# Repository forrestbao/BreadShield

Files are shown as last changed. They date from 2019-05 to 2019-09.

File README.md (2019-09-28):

# BreadShield

BreadShield is a shield that maps Arduino pins to breadboard ties without jumper wires. It inserts into both of them, firmly bridging them together mechanically and electrically.

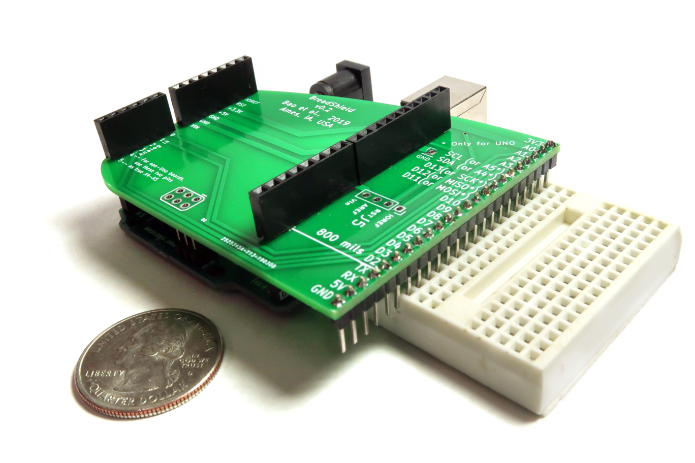
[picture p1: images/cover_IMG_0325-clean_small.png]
A breadshield


Watch [this video](https://www.youtube.com/watch?v=qSHss7gq7b0) to see BreadShield in action! 

To order, scroll down to see our distributors. 

# Why

Many projects start with connecting an Arduino and a breadboard using jumper wires. But jumper wires can easily become too many to manage, forming a mess of spaghetti that is difficult to trace, debug, and swap: 

Too mamy jumper wires can lead to a messy project that is hard to manage.

#Introducing BreadShield: The Arduino shield for breadboards

Like you, we have suffered enough. One day we asked, what if all of those messy jumper wires could become one shield? So BreadShield was born. With BreadShield, the messy project above can be simplified into: 

BreadShield connects an Arduino Uno with an HD44780 LCD with only 1 jumper wire, instead of 11 parallel jumper wires above.

# BreadShield vs. jumper wires

Connecting Arduino Uno to a HD44780 display, in jump wires. vs. in BreadShield

Connecting Arduino Uno to two servo motors, in jump wires. vs. in BreadShield

Connecting Arduino Uno to a row of LEDs, in jump wires. vs. in BreadShield

# No more choosing between shields or breadboards

Before, you cannot use shields together with breadboards because the jumper wires occupy sockets for shields. No more! With BreadShield, you can use both, simultaneously:

By BreadShield, you can use shields and breadboard together.

# Pinout of Breadshield

BreadShield pinout

# Organization of files in the repo
* KiCAD: the KiCAD files of the PCB
* demo: programs and documentations for demos
* images: some images of BreadShield

# License
BreadShield (c) by Forrest Sheng Bao et al.

BreadShield is licensed under a
Creative Commons Attribution-ShareAlike 4.0 International License.

You should have received a copy of the license along with this
work. If not, see <http://creativecommons.org/licenses/by-sa/4.0/>.

A copy of this license is in the file `license.md`.

# Where to buy
* [Tindie, by the author himself](https://www.tindie.com/products/edit/breadshield/) 
* [ARMWorks, 1 or 3-pack](https://andahammer.com/index.php?route=product/product&path=68&product_id=299)
* [Mouser](https://www.mouser.com/Search/Refine?FS=TRUE&N=4246651945+4292906361)
* [Crowd Supply](https://www.crowdsupply.com/loser/breadshield)

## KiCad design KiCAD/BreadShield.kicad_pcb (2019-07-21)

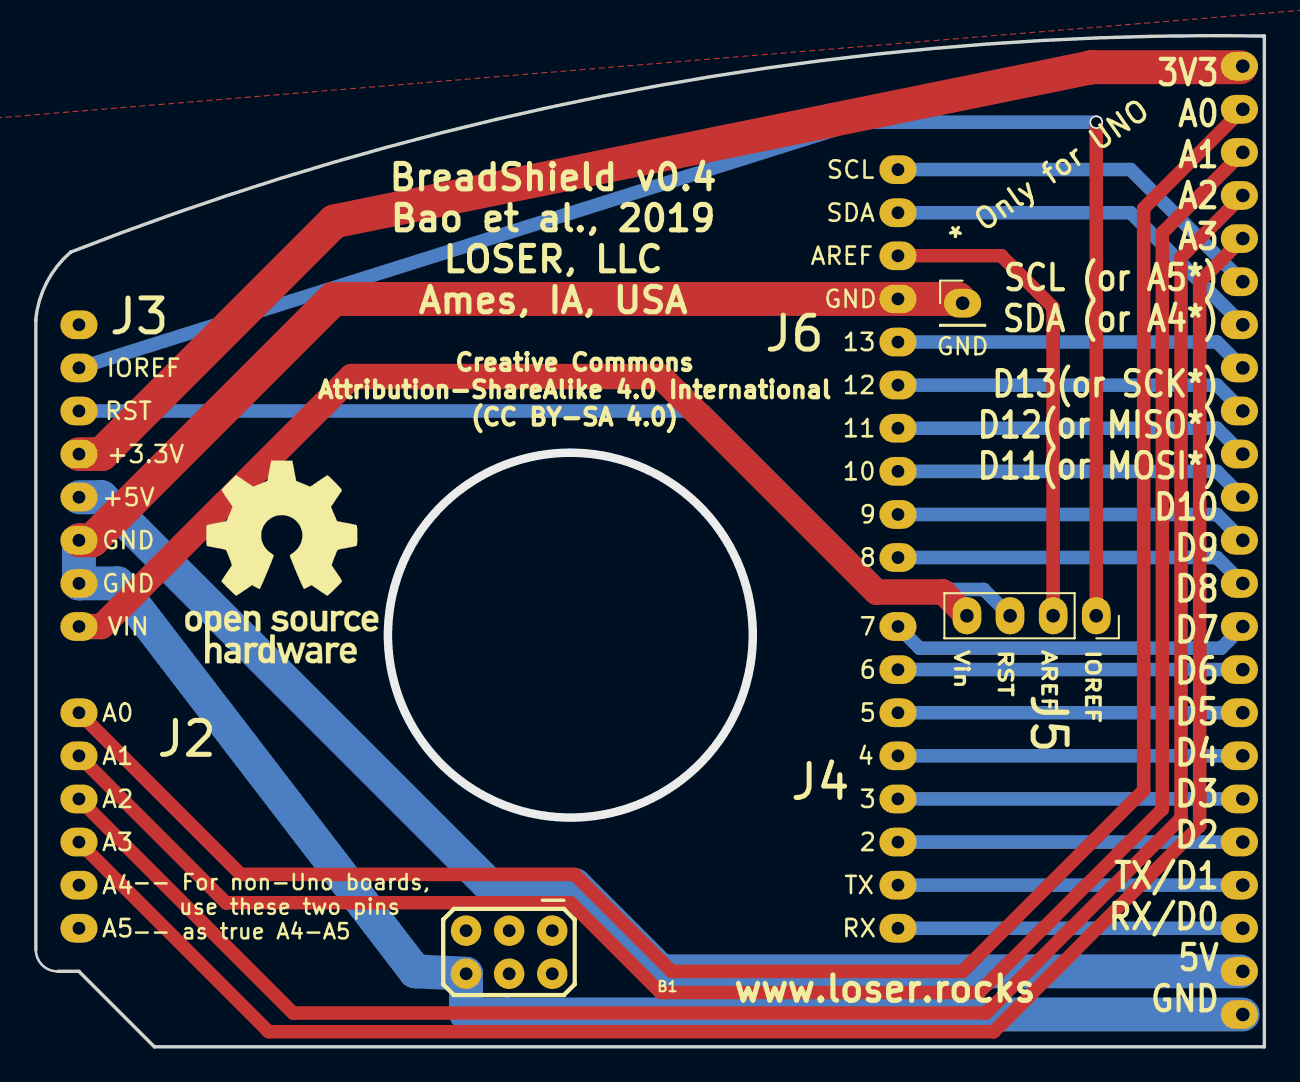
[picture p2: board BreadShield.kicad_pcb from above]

Board: 2 copper layers, 72.4 x 59.6 mm, 4 parts (1 on the bottom side), 27 nets.

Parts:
B1: ARDUINO_UNO_R3_SHIELD_ICSP; UNO_R3_SHIELD_ICSP
GND: PinHeader_1x01_P2.54mm_Vertical
J1: Conn_01x23_Male; PinHeader_1x23_P2.54mm_Vertical
J5: Conn_01x04_Female; PinSocket_1x04_P2.54mm_Vertical

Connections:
/3V3: B1.3.3V, J1.23
/5V: B1.5V, J1.2
/A0: B1.A0, J1.22
/A1: B1.A1, J1.21
/A2: B1.A2, J1.20
/A3: B1.A3, J1.19
/AREF: B1.AREF, J5.2
/D2: B1.D2, J1.5
/D3: B1.D3, J1.6
/D4: B1.D4, J1.7
/D5: B1.D5, J1.8
/D6: B1.D6, J1.9
/D7: B1.D7, J1.10
/D8: B1.D8, J1.11
/D9: B1.D9, J1.12
/D10: B1.D10, J1.13
/GND: B1.GND@, B1.GND_, GND.1, J1.1
/IOREF: B1.IORE, J5.1
/MISO_D12: B1.D12, J1.15
/MOSI_D11: B1.D11, J1.14
/RES: B1.RES, J5.3
/RX: B1.RX, J1.3
/SCK_D13: B1.D13, J1.16
/SCL_A5: B1.SCL, J1.18
/SDA_A4: B1.SDA, J1.17
/TX: B1.TX, J1.4
/Vin: B1.VIN, J5.4

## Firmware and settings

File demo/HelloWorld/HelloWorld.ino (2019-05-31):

/*

  by Forrest Sheng Bao
  for BreadShield project 
  March, 2019 

  This demo code is modified from the Hello,World example of 
  LiquidCrystal library 
  http://www.arduino.cc/en/Tutorial/LiquidCrystal

  Library originally added 18 Apr 2008
  by David A. Mellis
  library modified 5 Jul 2009
  by Limor Fried (http://www.ladyada.net)
  example added 9 Jul 2009
  by Tom Igoe
  modified 22 Nov 2010
  by Tom Igoe

 
  The circuit (different from default LiquidCrystal's):
 * VSS to GND on BreadShield  -- one end of a potentiometer
 * VDD to 5V on BreadShield  -- the other end of the potentiometer
 * VEE/V0 to RX on BreadShield -- middle pin of the potentiometer
 * RS to TX on BreadShield
 * RW to GND USE A JUMPWIRE -- not by pulling D2 to low
 * E/enable to D3 on BreadShield
 * LCD D4 pin to digital pin 8 on BreadShield
 * LCD D5 pin to digital pin 9 on BreadShield
 * LCD D6 pin to digital pin 10 on BreadShield
 * LCD D7 pin to digital pin 11 on BreadShield
 * LCD backlight Anode to digital pin 12 on BreadShield
 * LCD backlight kathode to digital pin 13 on BreadShield
 
 When programming the Arduino, please disconnect the GND pin of the potentiometer. 
 Otherwise, RX voltage will not be alternated by data but fixed by the potentiometer. 
 
 For unknown reasons, R/W has to be hardwired to GND rather than by pulling D2 to low. 
 
 */

// include the library code:
#include <LiquidCrystal.h>

// initialize the library with the numbers of the interface pins
LiquidCrystal lcd(1, 3, 8, 9, 10, 11);


void setup() {
  // set up the LCD's number of columns and rows: 
  lcd.begin(16, 2);
  // Print a message to the LCD.
  lcd.print("BreadShield is");
  lcd.setCursor(0, 1);  
  lcd.print("awesome! ");

  pinMode(12,OUTPUT);
  digitalWrite(12,HIGH); // backlit anode
  
  pinMode(13,OUTPUT);
  digitalWrite(13,LOW); //  backlit kathode
}

void loop() {
  // set the cursor to column 0, line 1
  // (note: line 1 is the second row, since counting begins with 0):
// lcd.setCursor(10, 1);
  // print the number of seconds since reset:
//  lcd.print(millis()/1000);
 
}

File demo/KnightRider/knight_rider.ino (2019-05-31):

/*
  Blink
  Turns on an LED on for one second, then off for one second, repeatedly.
 
  This example code is in the public domain.
 */
 
// Pin 13 has an LED connected on most Arduino boards.
// give it a name:
int led = 4;
int base = 2; 
int analogPin= A2;
int analogValue = 0; 
float blinkInterval = 200; 

// the setup routine runs once when you press reset:
void setup() {                
// set all digital pins (except RX/TX as outputs) 
  for (int i=0; i< 13; i++){
    led = base + i ; 
    pinMode(led, OUTPUT);
  } 
  Serial.begin(9600);
}

// the loop routine runs over and over again forever:
void loop() {
  
  analogValue = analogRead(analogPin);
  analogValue = analogValue >> 2;
  Serial.print(analogValue);
  Serial.print("\t");
  blinkInterval = float(analogValue)*100./256.+10;
  Serial.println(blinkInterval);
  for (int i=0; i< 13; i++){
    led = base + i;
    digitalWrite(led, HIGH);   // turn the LED on (HIGH is the voltage level)
    delay(blinkInterval);               // wait 
    digitalWrite(led, LOW);    // turn the LED off by making the voltage LOW
  }
}

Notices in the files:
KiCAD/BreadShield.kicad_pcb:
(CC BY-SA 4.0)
